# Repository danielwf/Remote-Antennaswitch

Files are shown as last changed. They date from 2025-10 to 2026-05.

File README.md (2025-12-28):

# ESP32 Antenna Switch 

for the Remote Club Station of [DARC Bremen (i04)](https://darc.de/i04)\
\
**This is a draft!** \
There is no guarantee of functionality. Use at your own risk. 

## Description

The antenna switch can be controlled via the ESP32 either by USB or WiFi. Two buttons can be connected for local control. The switched inputs and outputs are also indicated by LEDs.  
The 3 inputs and 5 outputs are switched using two bistable relays per connection (Finder 40.31.6.006.0000). These are controlled by drivers that can be put into sleep mode between switching operations (DRV8833PWP). This reduces power consumption and minimizes interference from busy switching regulators. In addition, the USB port of the ESP32 is sufficient for the power supply.  
The relay drivers are controlled via an I2C 16-bit port expander (MCP23017).  
In addition, a PWR/SWR meter is available via an I2C AD converter (ADS1115IDGS). This is used to prevent switching during transmission. It can also be used for transmitter-independent measurement to display transmission power and SWR in the remote software.  

Since both the relay switching and the reading of the SWR bridge are communicated via I2C, other controllers can also be used if necessary. It is also possible to connect several boards together. For this purpose, the I2C addresses can be easily adjusted via the solder pads.  

## Built

**Kicad 9:**
You maybe need the KiCad symbol and footprint for the ESP32 Mini(Wemos D1 Mini) [https://github.com/r0oland/ESP32_mini_KiCad_Library](https://github.com/r0oland/ESP32_mini_KiCad_Library) - Thanks to [Johannes Rebling](https://github.com/r0oland)

[Schematic](schematic.pdf)

**Hardware:**
Everything you need to prepare your PCB ordering with KiCAD is included. It is best to use a corresponding KiCAD plugin for this.  
In "BOM.ods" you will find the material list with links to the item numbers at Mouser and Reichelt. In the table, you can easily adjust how many devices the parts should be ordered for (as of Oct-25).  
The BOM includes a housing that is well suited for this purpose. The drill holes for the circuit board can be easily marked with an unassembled PCB (which should be done first). "Panels.svg" contains the drill holes and labels for the buttons, LEDs, and connection sockets. These can be produced using a vinyl cutter or laser engraver, for example. The easiest way to create the USB socket is to drill a 14 mm hole and produce a cover for it using a 3D printer. A template for this is also included.  
Once the parts have been assembled, the Arduino code for the ESP32 can be uploaded. You will find this in “AntennaSwitch-ESP32.ino”. For later OTA updates via the web interface, you can use “AntennaSwitch-ESP32.ino.bin”.  

## Usage WIFI
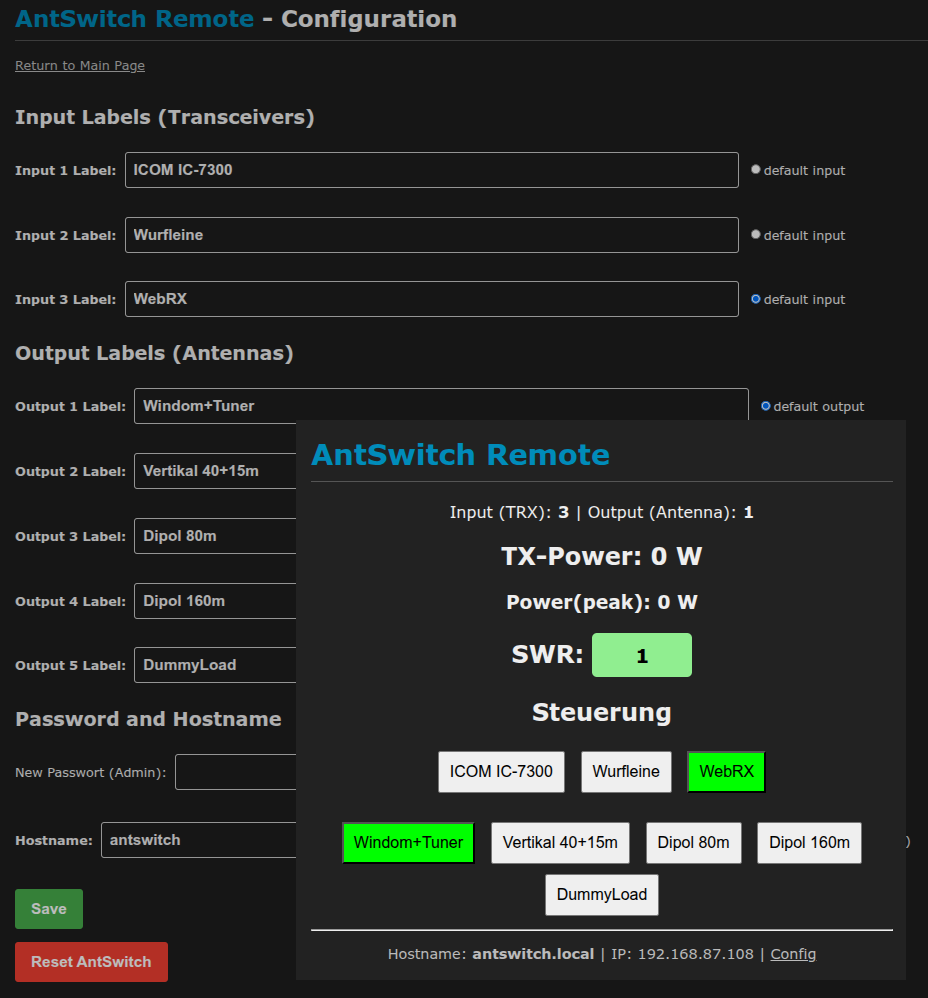
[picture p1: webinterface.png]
 After you have uploaded the Arduino code to the ESP32, you must connect to the “AntSwitch-Config” Wi-Fi network and set up the desired Wi-Fi network via the captive portal. 
Once the device is connected to your home network, you can configure it via 'https://antswitch.local' such as a new host name and the labels for the connectors. **Default password for 'admin' is 'antswitch'**.  
You can also switch via API (example: you want to use CURL in your shell/script, maybe in combination with rigctld). Examples: 
- http://antswitch.local/api/status (for JSON-Status)
- http://antswitch.local/api/switch?input=1 (set input to 1)
- http://antswitch.local/api/switch?output=2 (set output to 2)
Setup via API:
- http://antswitch.local/api/switch?iLabel1=IC-7300 (set Label of input 1)
- http://antswitch.local/api/switch?oLabel2=Windom-Antenna (set Label of output 2)
- http://antswitch.local/api/switch?defaultInput=1 (set default input after switch-on)
- http://antswitch.local/api/switch?defaultOutput=2 (set default output after switch-on)
- http://antswitch.local/api/status?maxTxPower=380 (Calibration of SWR-Meter acc to windings on transformer- or just try out and compare to other SWR-Meter)

## Usage USB-serial
The device can also be controlled via the USB-serial interface (115200 baud). With “GET:NET” you can display the current IP address.  
Serial commands: 
```
       ____DESCRIPTION__________INPUT_________________________RESPONSE___________________________________  
       Switching  
       Switch Input (TRX)          SET:I<Index>                  ACK:I<CurrentInput>,O<CurrentOutput>  
                                                                ERR:BLOCKED_TX (if P_fwd > 5.0W)  
       Switch Output (Antenna)     SET:O<Index>                  ACK:I<CurrentInput>,O<CurrentOutput>  
                                                                ERR:BLOCKED_TX (if P_fwd > 5.0W)  
       ___________________________________________________________________________________________________
       Configuration
       Set Input Label             SET_LABEL I <Index> <Label>   ACK:LABEL_OK
                                                                ERR:INVALID_LENGTH
       Set Output Label            SET_LABEL O <Index> <Label>   ACK:LABEL_OK
                                                                ERR:INVALID_LENGTH
       Set Default Input           SET_DEFAULT I <Index>         ACK:DEFAULT_OK
                                                                ERR:INVALID_INDEX
       Set Default Output          SET_DEFAULT O <Index>         ACK:DEFAULT_OK
                                                                ERR:INVALID_INDEX
       Set Admin Password          SET_PASS <Password>           ACK:PASS_OK
                                                                ERR:INVALID_LENGTH (min 8 chars)
       ___________________________________________________________________________________________________
       Status and Measurements
       Get All Status & Meas.      GET:STATUS                    ACK:STATUS,PF=x.x,PP=x.x,SWR=x.xx
       Get Forward Power (Formatted) GET:PF                        ACK:PF=x.x
       Get Peak Power (Formatted)  GET:PP                        ACK:PP=x.x
       Get SWR Value (Formatted)   GET:SWR                       ACK:SWR=x.xx
       Get Forward Power (Numeric) NUM:PF                        [x.x] (Unformatted numeric value)
       Get Peak Power (Numeric)    NUM:PP                        [x.x] (Unformatted numeric value)
       Get SWR Value (Numeric)     NUM:SWR                       [x.xx] (Unformatted numeric value)
       Get IP and Hostname         GET:NET                       ACK:NET,IP=x.x.x.x,HOST=<Hostname>
       Get Input Label             GET_LABEL I <Index>           ACK:LABEL_I<Index>=<Label>
       Get Output Label            GET_LABEL O <Index>           ACK:LABEL_O<Index>=<Label>
```

## Contributing

Pull requests are welcome. For major changes, please open an issue first
to discuss what you would like to change.

## License

[CC BY-SA 4.0](https://creativecommons.org/licenses/by-sa/4.0/) 

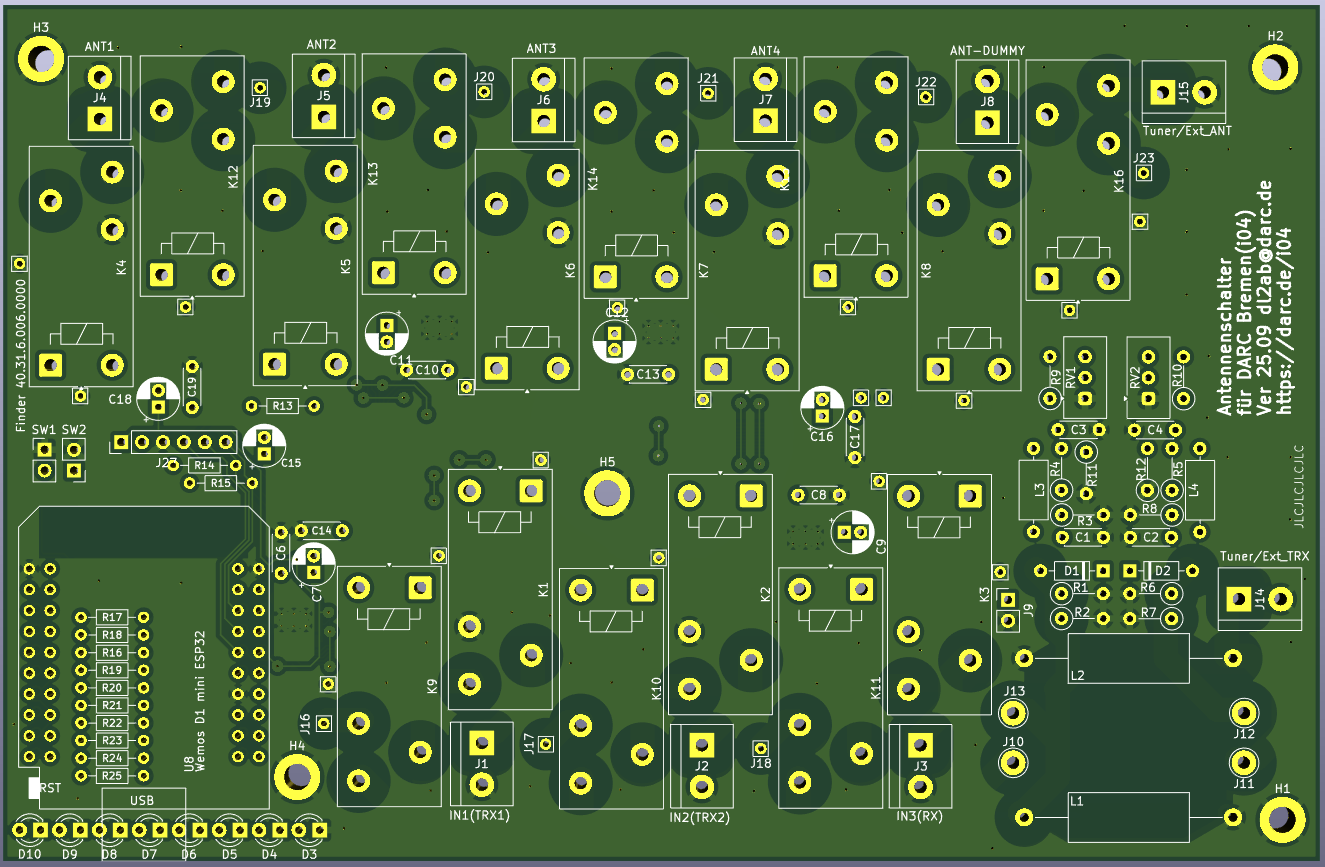
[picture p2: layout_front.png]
(Layout front)

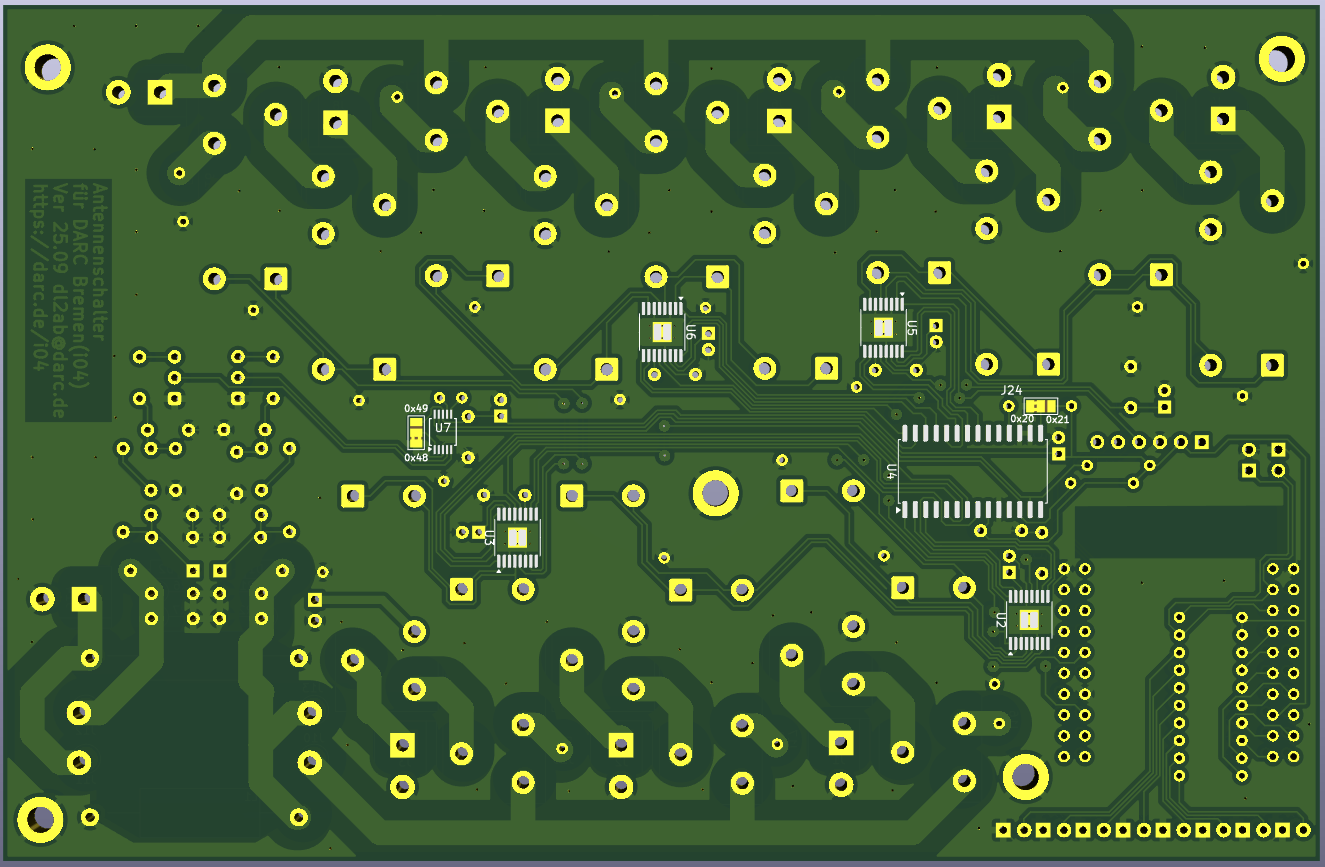
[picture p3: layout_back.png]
(Layout back)


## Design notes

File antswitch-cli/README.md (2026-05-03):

The antenna switch can be controlled via a browser interface or a serial interface. No special software is required for either method.  
However, it should be noted that a serial connection is not necessarily recommended if, for example, common-mode currents are expected at the switch due to an unsuitable antenna. Generally, a connection via the station's Wi-Fi network is recommended.  
There are some use cases where you might want to control a Wi-Fi-connected antenna switch using the Linux shell.  
This is now possible with Antswitch-CLI.  
  
antswitch-cli.config:  
Configuration of addresses and commands (admin users are only relevant for the web interface, see below)  
  
antswitch-cli.frq-map:  
Overview of frequencies, antennas, and tuners to be used.  
--> This file is helpful to other applications, e.g., for using remote transceiver software.  
Syntax: [Start Frequency (Hz)]-[End Frequency (Hz)]=[Antenna Number]|[TUNER (EXTERN/INTERN/AUS)]
  
antswitch-cli.port:  
Labels and Default Ports  
--> This file is helpful to other applications, e.g., for using remote transceiver software.  
(The script can read this information from the hardware and write it to the file)  
  
install.sh:  
Please read this beforehand; it contains information on installing the additional web interface.  
  
antswitch.php and antswitch-admin.php:  
Web interface for antenna switching via Antswitch-Cli.  
  
Although the antenna switch has its own web interface, there are reasons for not making it externally accessible. Furthermore, the antswitch-cli web interface is easier to embed as an iframe.  
  
The frequency map file can be edited and labels from the antenna switch can be imported via antswitch-admin.php. User management is not explained further here. However, it is advisable to install a PAM module for Apache, which, for example, manages access to the "/var/www/html/login" subfolder.

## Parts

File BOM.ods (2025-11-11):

 |  |  |  | per 07-Sep-2025 for 3 Units
Reference | Value | Footprint | Qty/Unit | Price/Unit | Builds | Qty/Batch | Price/Batch | Distributor | Link
C1,C2,C3,C4 | 1.2nF | Capacitor_THT:C_Disc_D4.3mm_W1.9mm_P5.00mm | 4 | 0,178 € | 3 | 12 | 2,14 € | Mouser | https://www.mouser.de/ProductDetail/810-FG28C0G2E122JNT6
C6,C8,C10,C13,C14,C17,C19 | 100nF | Capacitor_THT:C_Disc_D4.3mm_W1.9mm_P5.00mm | 7 | 0,077 € | 3 | 21 | 1,62 € | Mouser | https://www.mouser.de/ProductDetail/594-K104K15X7RF5WH5
C7,C9,C11,C12,C15,C16,C18 | 2.2uF | Capacitor_THT:CP_Radial_D5.0mm_P2.00mm | 7 | 0,124 € | 3 | 21 | 2,60 € | Mouser | https://www.mouser.de/ProductDetail/80-ESH225M050AC3KA
D1,D2 | BAT43 | Diode_THT:D_DO-35_SOD27_P7.62mm_Horizontal | 2 | 0,112 € | 3 | 6 | 0,67 € | Mouser | https://www.mouser.de/ProductDetail/511-BAT43
D3, D4, D5, D6, D7, D8, D9, D10 | LED1 | LED_THT:LED_D3.0mm | 8 | 0,147 € | 3 | 24 | 3,53 € | Mouser | https://www.mouser.de/ProductDetail/604-WP710A10CGCK
J1, J2, J3, J4, J5, J6, J7, J8, J14, J15 | IN/OUTPUT | PL-Connector | 10 | 1,720 € | 3 | 30 | 51,60 € | Mouser | https://www.mouser.de/ProductDetail/601-25-7350
J9 | ANT-RX | SMA-Connector | 1 | 8,320 € | 3 | 3 | 24,96 € | Mouser | https://www.mouser.de/ProductDetail/523-132142
L3,L4 | 47uH | Inductor_THT:L_Axial_L7.0mm_D3.3mm_P10.16mm_Horizontal_Fastron_MICC | 2 | 0,335 € | 3 | 6 | 2,01 € | Mouser | https://www.mouser.de/ProductDetail/871-B82141A1473J000
R1,R2,R6,R7 | 100R/1W | Resistor_THT:R_Axial_DIN0207_L6.3mm_D2.5mm_P5.08mm_Vertical | 4 | 0,140 € | 3 | 12 | 1,68 € | Mouser | https://www.mouser.de/ProductDetail/279-ROX1G100R
R3,R8 | 1M2 | Resistor_THT:R_Axial_DIN0207_L6.3mm_D2.5mm_P5.08mm_Vertical | 2 | 0,086 € | 3 | 6 | 0,52 € | Mouser | https://www.mouser.de/ProductDetail/603-MFR-25FRF52-1M2
R4,R5 | 8,2k | Resistor_THT:R_Axial_DIN0207_L6.3mm_D2.5mm_P5.08mm_Vertical | 2 | 0,072 € | 3 | 6 | 0,43 € | Mouser | https://www.mouser.de/ProductDetail/594-5063JD8K200FT
R9,R10 | 2.2k | Resistor_THT:R_Axial_DIN0207_L6.3mm_D2.5mm_P5.08mm_Vertical | 2 | 0,086 € | 3 | 6 | 0,52 € | Mouser | https://www.mouser.de/ProductDetail/594-MBB02070C2201FCT
R13,R14,R15,R17,R18 | 10k | Resistor_THT:R_Axial_DIN0204_L3.6mm_D1.6mm_P7.62mm_Horizontal | 5 | 0,068 € | 3 | 15 | 1,02 € | Mouser | https://www.mouser.de/ProductDetail/594-MBB02070C1002FRP
R16,R19,R20,R21,R22,R23,R24,R25 | 220 | Resistor_THT:R_Axial_DIN0204_L3.6mm_D1.6mm_P7.62mm_Horizontal | 8 | 0,072 € | 3 | 24 | 1,73 € | Mouser | https://www.mouser.de/ProductDetail/594-5063JD220R0FT
RV1,RV2 | 4.7k | Potentiometer_THT:Potentiometer_Vishay_T93YA_Vertical | 2 | 1,670 € | 3 | 6 | 10,02 € | Mouser | https://www.mouser.de/ProductDetail/72-T93YA472KT20
SW1, SW2 | Switch/Button | Push Button Panel Mount | 2 | 5,140 € | 3 | 6 | 30,84 € | Mouser | https://www.mouser.de/ProductDetail/612-PV2F640NN
U2,U3,U5,U6 | DRV8833PWP | Package_SO:HTSSOP-16-1EP_4.4x5mm_P0.65mm_EP3.4x5mm_Mask2.46x2.31mm_ThermalVias | 4 | 1,720 € | 3 | 12 | 20,64 € | Mouser | https://www.mouser.de/ProductDetail/595-DRV8833PWPR
U4 | MCP23017_SO | Package_SO:SOIC-28W_7.5x17.9mm_P1.27mm | 1 | 1,390 € | 3 | 3 | 4,17 € | Mouser | https://www.mouser.de/ProductDetail/579-MCP23017-E-SO
U7 | ADS1115IDGS | Package_SO:TSSOP-10_3x3mm_P0.5mm | 1 | 5,410 € | 3 | 3 | 16,23 € | Mouser | https://www.mouser.de/ProductDetail/595-ADS1115IDGST
Delivery |  |  |  |  |  |  | 0,00 € | Mouser
Total Mouser | 176,92 € | https://www.mouser.de/ProjectManager/ProjectDetail.aspx?AccessID=3c516e5cf0
U8 | Wemos D1 mini ESP32 | ESP32_mini:ESP32_mini | 1 | 10,500 € | 3 | 3 | 31,50 € | Reichelt | https://www.reichelt.de/de/de/shop/produkt/d1_mini_pro_-_esp32-wroom_board_cp2104-357465
Metal Housing | TEKO 385 | 253 x 160 x 70 | 1 | 41,700 € | 3 | 3 | 125,10 € | Reichelt | https://www.reichelt.de/de/de/shop/produkt/alugehaeuse_253_x_160_x_70_mm_silber-21198
50 Screws M3x10 (for Connectors) | M3x10 | M3 | 1 | 1,750 € | 3 | 3 | 5,25 € | Reichelt | https://www.reichelt.de/de/de/shop/produkt/pan_head_schrauben_kreuzschlitz_pzd_m3_10mm_50_stueck-65753
100 Washers 3.2mm | Washers | M3 | 1 | 1,550 € | 3 | 3 | 4,65 € | Reichelt | https://www.reichelt.de/de/de/shop/produkt/unterlegscheiben_3_2_mm_100_stueck-65763
100 Fan Washers 3.2mm | Fan Washers | M3 | 1 | 1,750 € | 3 | 3 | 5,25 € | Reichelt | https://www.reichelt.de/de/de/shop/produkt/faecherscheiben_3_2_mm_100_stueck-65789
100 Solder Lugs M3 | Solder Lugs | M3 | 1 | 3,400 € | 3 | 1 | 3,40 € | Reichelt | https://www.reichelt.de/de/de/shop/produkt/loetoesen_fuer_m3_100-er_pack-231423
100 Screw Nuts M3 | Screw Nuts | M3 | 1 | 4,550 € | 3 | 2 | 9,10 € | Reichelt | https://www.reichelt.de/de/de/shop/produkt/sechskantmuttern_edelstahl_a2_m3_100_stueck-72592
Feets for Housing | Rubber feet | M3 | 4 | 0,250 € | 3 | 12 | 3,00 € | Reichelt | https://www.reichelt.de/de/de/shop/produkt/anschraubpuffer_17_5_mm_9_mm_schwarz-8172
Spacer | Spacer | M3 | 5 | 0,290 € | 3 | 15 | 4,35 € | Reichelt | https://www.reichelt.de/de/de/shop/produkt/distanzhuelsen_metall_6-kant_m3_8mm-231466
K1,K2,K3,K4,K5,K6,K7,K8,K9,K10,K11,K12,K13,K14,K15,K16 | Finder 40.31.6.006.0000 | Relay_THT:Relay_SPDT_Finder_40.31 | 16 | 7,250 € | 3 | 48 | 348,00 € | Reichelt | https://www.reichelt.de/de/de/shop/produkt/bistabiles_steckrelais_6v_1_wechsler_10a-225229
L1/2 | BN43-202 | BN43-202 | 1 | 0,990 € | 3 | 3 | 2,97 € | Reichelt | https://www.reichelt.de/de/de/shop/produkt/doppellochkern_aussen_13_7_mm_innen_4_mm_al_2890-32310
Discount |  |  |  |  |  |  | -15,33 € | Reichelt
Delivery |  |  |  |  |  |  | 5,95 € | Reichelt
Total Reichelt | 533,19 € | https://www.reichelt.de/my/2288622
5x PCBs |  |  | Min. 5 | 10,05 | 1 | 1 | 10,05 € | JLCPCB
Delivery (DHL Express) |  |  |  | 18,32 | 1 | 1 | 18,32 € | JLCPCB
Total JLCPCB | 28,37 €
 |  |  |  |  |  | Total | 738,48 €

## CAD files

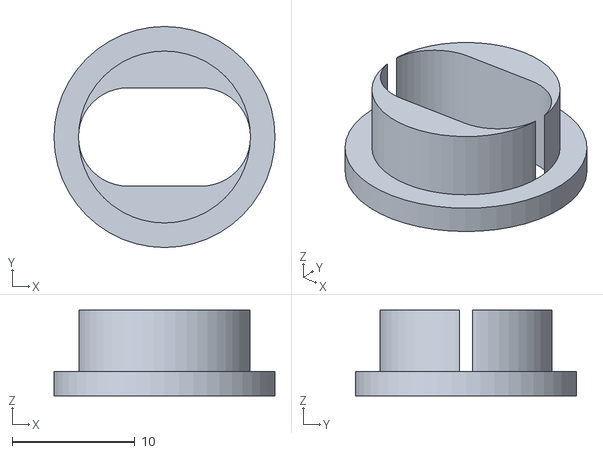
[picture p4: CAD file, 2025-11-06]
USB-C-14mm.stl
18.0 x 18.0 x 7.00

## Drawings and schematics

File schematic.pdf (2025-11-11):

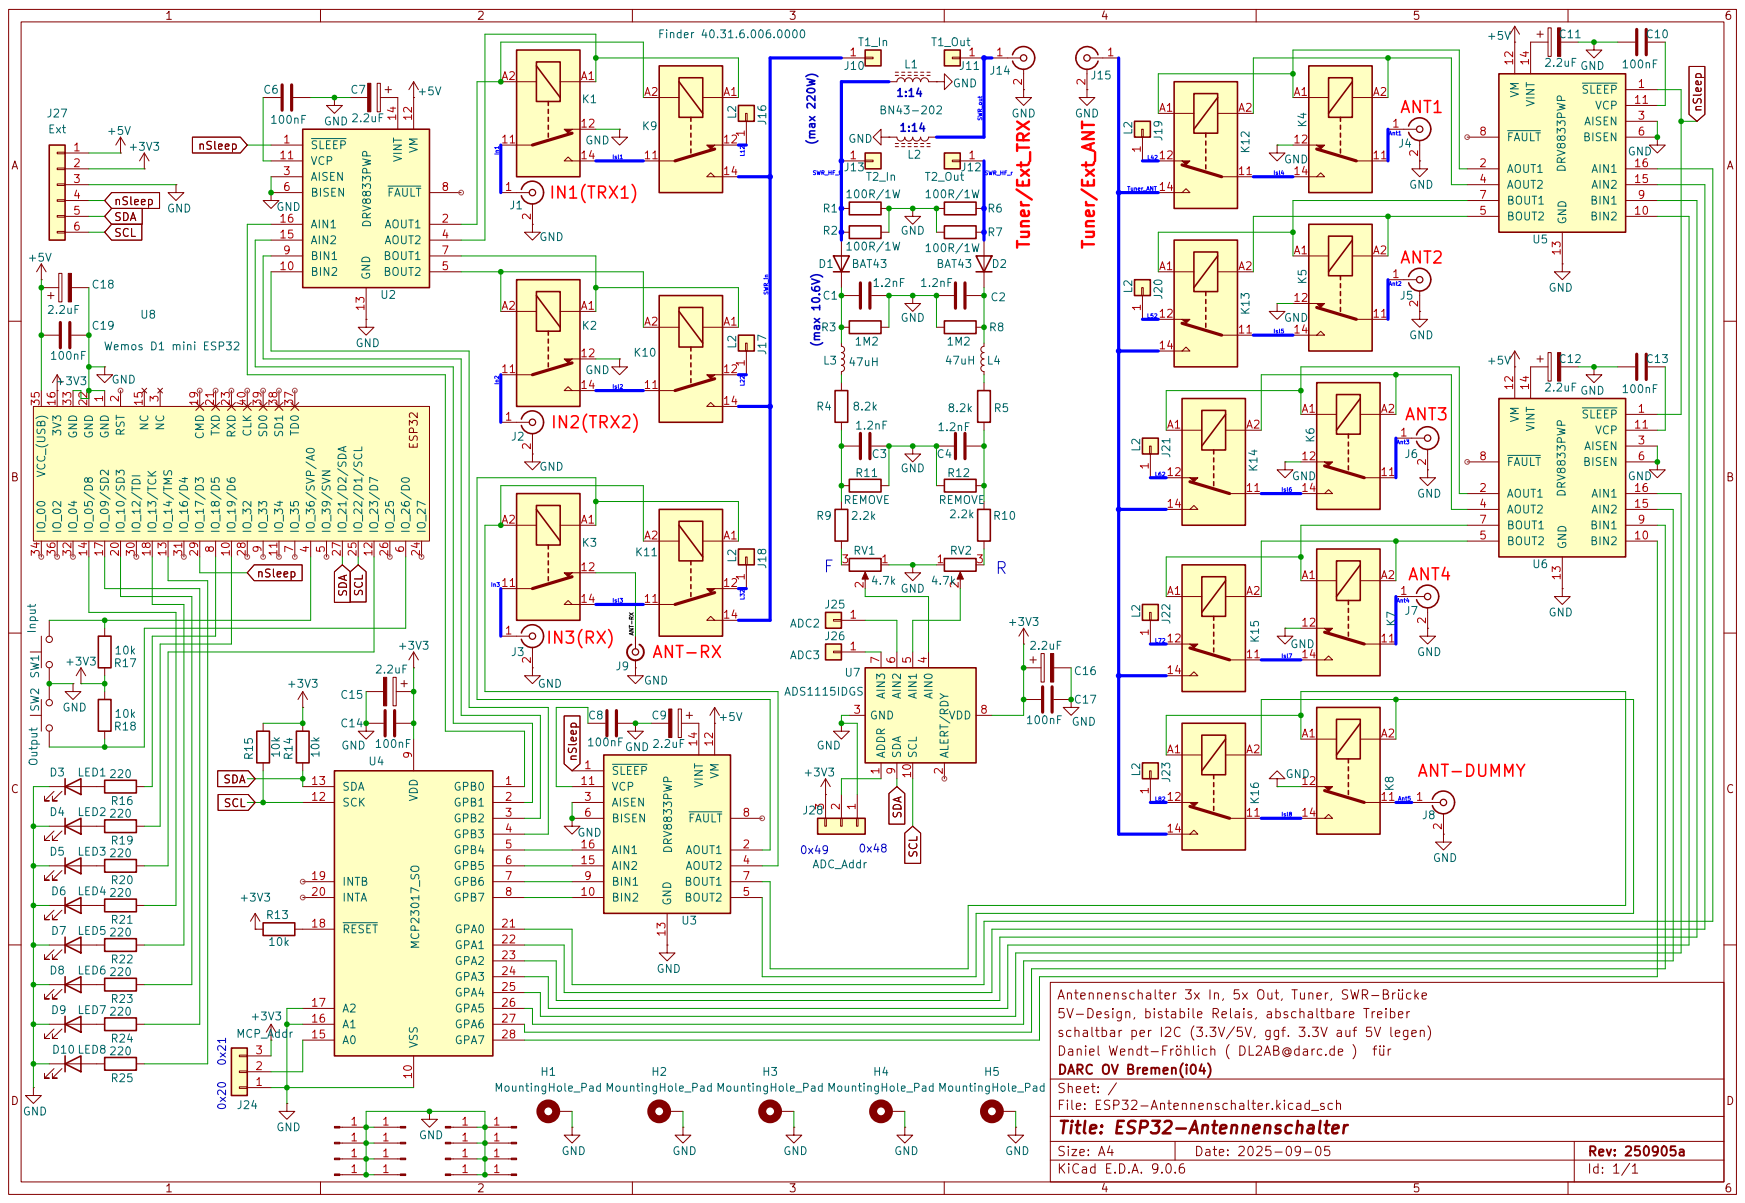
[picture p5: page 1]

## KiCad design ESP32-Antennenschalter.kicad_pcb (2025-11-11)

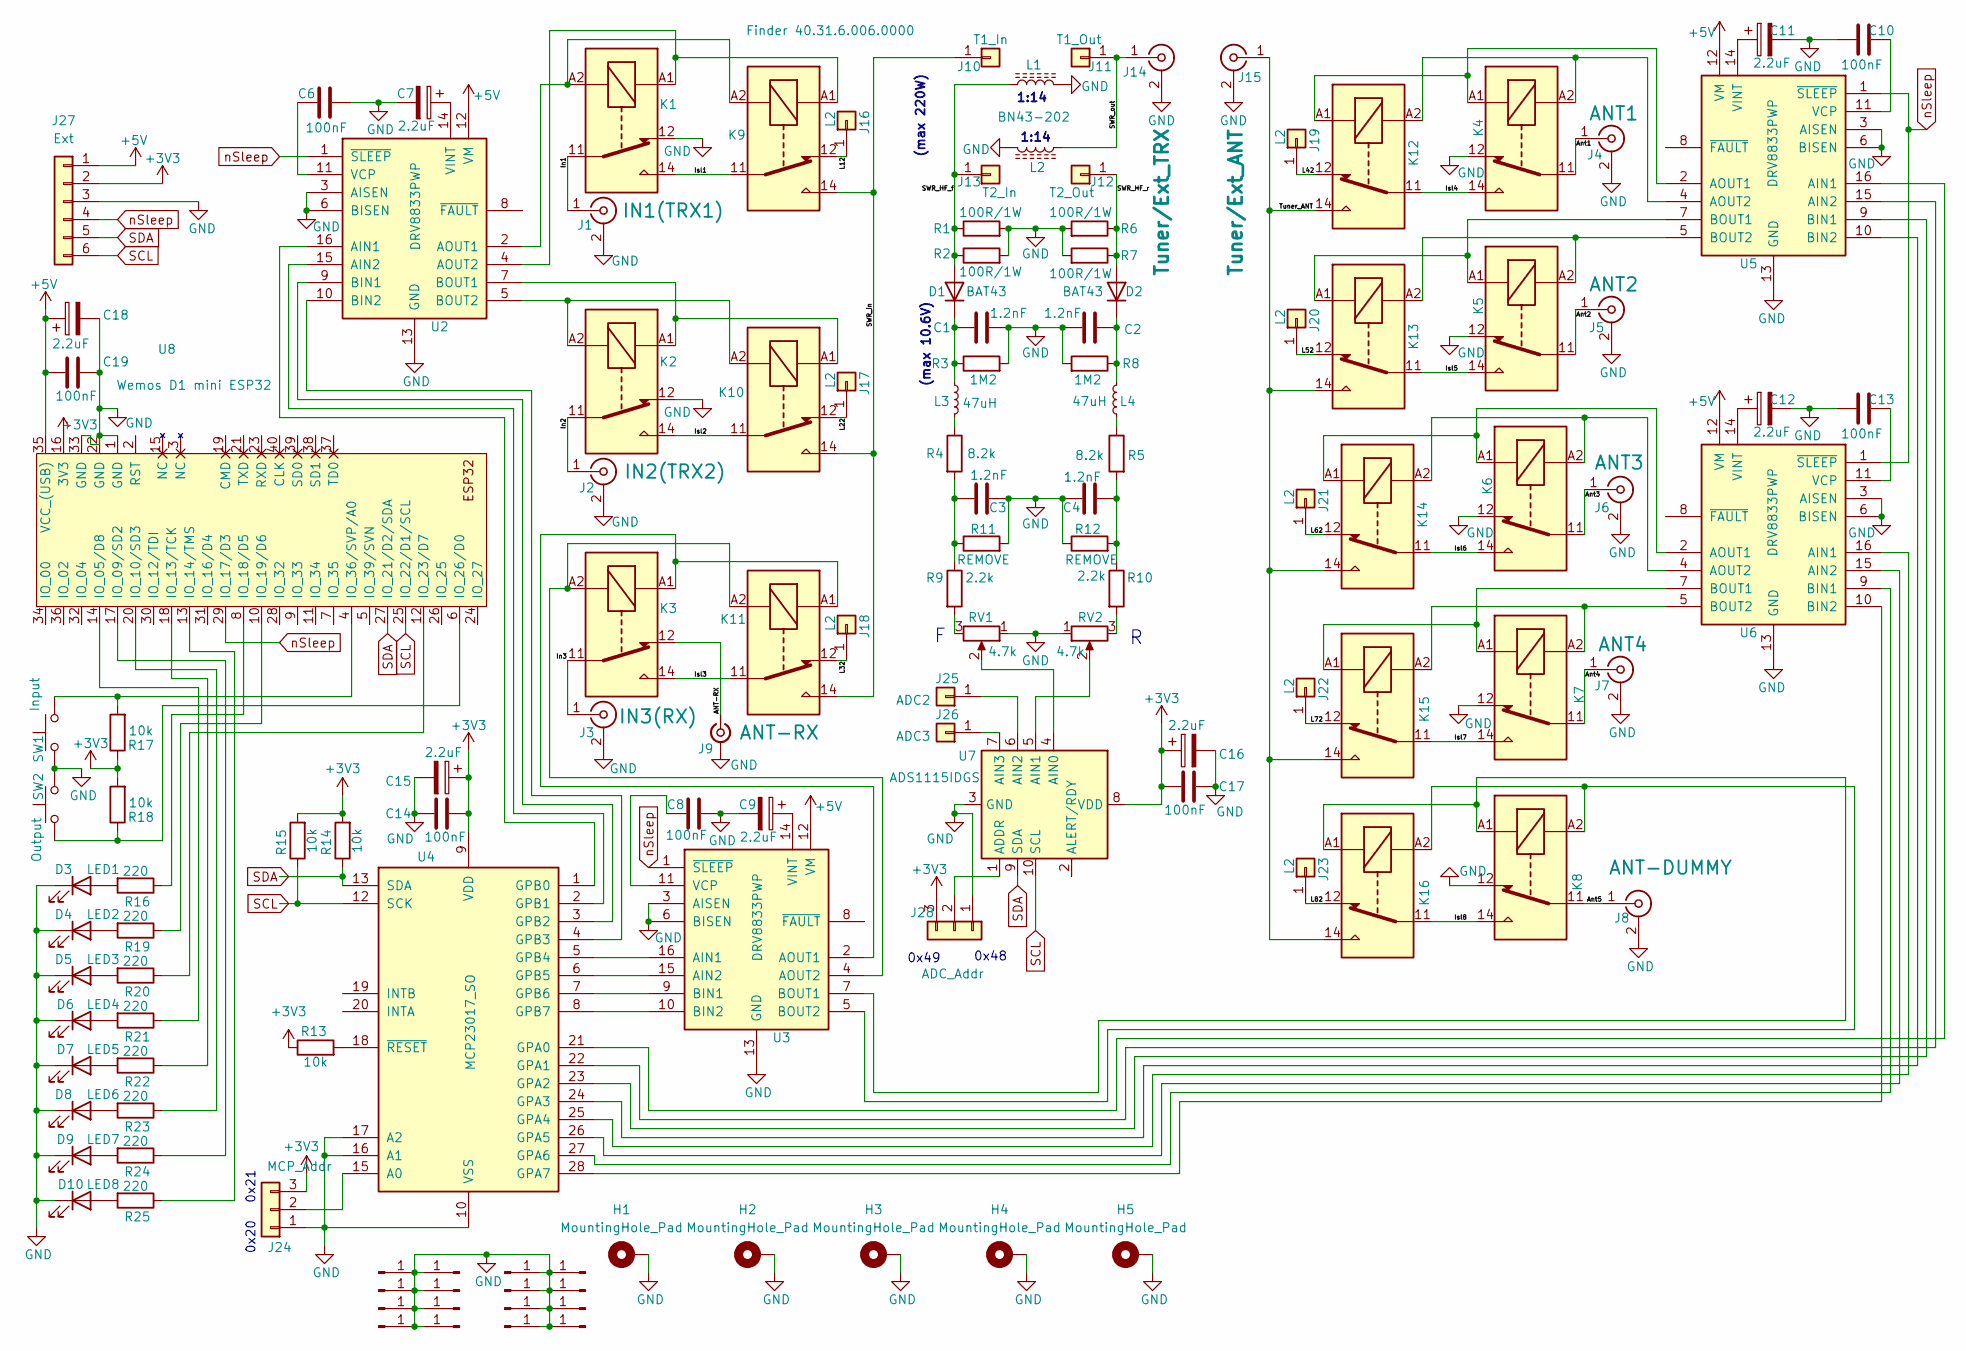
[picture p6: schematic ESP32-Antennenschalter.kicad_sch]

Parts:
C1, C2, C3, C4: 1.2nF; C_Disc_D4.3mm_W1.9mm_P5.00mm
C6, C8, C10, C13, C14, C17, C19: 100nF; C_Disc_D4.3mm_W1.9mm_P5.00mm
C7, C9, C11, C12, C15, C16, C18: 2.2uF; CP_Radial_D5.0mm_P2.00mm
D1, D2: BAT43; D_DO-35_SOD27_P7.62mm_Horizontal
D3: LED1; LED_D3.0mm
D4: LED2; LED_D3.0mm
D5: LED3; LED_D3.0mm
D6: LED4; LED_D3.0mm
D7: LED5; LED_D3.0mm
D8: LED6; LED_D3.0mm
D9: LED7; LED_D3.0mm
D10: LED8; LED_D3.0mm
H1, H2, H3, H4, H5: MountingHole_Pad; MountingHole_3.2mm_M3_DIN965_Pad_TopBottom
J1: IN1(TRX1); TerminalBlock_bornier-2_P5.08mm
J2: IN2(TRX2); TerminalBlock_bornier-2_P5.08mm
J3: IN3(RX); TerminalBlock_bornier-2_P5.08mm
J4: ANT1; TerminalBlock_bornier-2_P5.08mm
J5: ANT2; TerminalBlock_bornier-2_P5.08mm
J6: ANT3; TerminalBlock_bornier-2_P5.08mm
J7: ANT4; TerminalBlock_bornier-2_P5.08mm
J8: ANT-DUMMY; TerminalBlock_bornier-2_P5.08mm
J9: ANT-RX; PinHeader_1x02_P2.54mm_Vertical
J10: T1_In; Pin_D1.3mm_L11.0mm_LooseFit
J11: T1_Out; Pin_D1.3mm_L11.0mm_LooseFit
J12: T2_Out; Pin_D1.3mm_L11.0mm_LooseFit
J13: T2_In; Pin_D1.3mm_L11.0mm_LooseFit
J14: Tuner/Ext_TRX; TerminalBlock_bornier-2_P5.08mm
J15: Tuner/Ext_ANT; TerminalBlock_bornier-2_P5.08mm
J16, J17, J18, J19, J20, J21, J22, J23: L2; Pin_D0.7mm_L6.5mm_W1.8mm_FlatFork
J24: MCP_Addr; SolderJumper-3_P1.3mm_Bridged2Bar12_Pad1.0x1.5mm_NumberLabe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
J25: ADC2; Pin_D0.7mm_L6.5mm_W1.8mm_FlatFork
J26: ADC3; Pin_D0.7mm_L6.5mm_W1.8mm_FlatFork
J27: Ext; PinHeader_1x06_P2.54mm_Vertical
J28: ADC_Addr; SolderJumper-3_P1.3mm_Bridged2Bar12_Pad1.0x1.5mm_NumberLabe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
J29, J30, J31, J32, J33, J34, J35, J36, J37, J38, J39, J40, J41, J42, J43, J44: Conn_01x01_Pin; Pin_D0.7mm_L6.5mm_W1.8mm_FlatFork
K1, K2, K3, K4, K5, K6, K7, K8, K9, K10, K11, K12, K13, K14, K15, K16: Finder 40.31.6.006.0000; Relay_SPDT_Finder_40.31
L1, L2: BN43-202; L_Axial_L14.5mm_D5.8mm_P25.40mm_Horizontal_Fastron_HBCC
L3, L4: 47uH; L_Axial_L7.0mm_D3.3mm_P10.16mm_Horizontal_Fastron_MICC
R1, R2, R6, R7: 100R/1W; R_Axial_DIN0207_L6.3mm_D2.5mm_P5.08mm_Vertical
R3, R8: 1M2; R_Axial_DIN0207_L6.3mm_D2.5mm_P5.08mm_Vertical
R4, R5: 8.2k; R_Axial_DIN0207_L6.3mm_D2.5mm_P5.08mm_Vertical
R9, R10: 2.2k; R_Axial_DIN0207_L6.3mm_D2.5mm_P5.08mm_Vertical
R11, R12: REMOVE; R_Axial_DIN0207_L6.3mm_D2.5mm_P5.08mm_Vertical
R13, R14, R15, R17, R18: 10k; R_Axial_DIN0204_L3.6mm_D1.6mm_P7.62mm_Horizontal
R16, R19, R20, R21, R22, R23, R24, R25: 220; R_Axial_DIN0204_L3.6mm_D1.6mm_P7.62mm_Horizontal
RV1, RV2: 4.7k; Potentiometer_Vishay_T93YA_Vertical
SW1: Input; PinHeader_1x02_P2.54mm_Vertical
SW2: Output; PinHeader_1x02_P2.54mm_Vertical
U2, U3, U5, U6: DRV8833PWP; HTSSOP-16-1EP_4.4x5mm_P0.65mm_EP3.4x5mm_Mask2.46x2.31mm_The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
U4: MCP23017_SO; SOIC-28W_7.5x17.9mm_P1.27mm
U7: ADS1115IDGS; TSSOP-10_3x3mm_P0.5mm
U8: Wemos D1 mini ESP32; ESP32_mini

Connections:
+3V3: C14.1, C15.1, C16.1, C17.1, J24.3, J27.2, J28.3, R13.1, R14.2, R15.2, R17.1, R18.2, U4.9 (VDD), U7.8 (VDD), U8.16 (3V3)
+5V: C18.1, C19.2, J27.1, U2.12 (VM), U3.12 (VM), U5.12 (VM), U6.12 (VM), U8.35 (VCC_(USB))
/ANT-RX: J9.1 (In), K3.12
/Ant1: J4.1 (In), K4.11
/Ant2: J5.1 (In), K5.11
/Ant3: J6.1 (In), K6.11
/Ant4: J7.1 (In), K7.11
/Ant5: J8.1 (In), K8.11
/In1: J1.1 (In), K1.11
/In2: J2.1 (In), K2.11
/In3: J3.1 (In), K3.11
/Isl1: K1.14, K9.11
/Isl2: K2.14, K10.11
/Isl3: K3.14, K11.11
/Isl4: K4.14, K12.11
/Isl5: K5.14, K13.11
/Isl6: K6.14, K14.11
/Isl7: K7.14, K15.11
/Isl8: K8.14, K16.11
/L12: J16.1, K9.12
/L22: J17.1, K10.12
/L32: J18.1, K11.12
/L42: J19.1, K12.12
/L52: J20.1, K13.12
/L62: J21.1, K14.12
/L72: J22.1, K15.12
/L82: J23.1, K16.12
/SWR_HF_f: D1.2 (A), J13.1, L1.1, R1.1, R2.1
/SWR_HF_r: D2.2 (A), J12.1, R6.1, R7.1
/SWR_in: J10.1, K9.14, K10.14, K11.14
/SWR_out: J11.1, J14.1 (In), L2.1
/Tuner_ANT: J15.1 (In), K12.14, K13.14, K14.14, K15.14, K16.14
GND: C1.2, C2.2, C3.2, C4.1, C6.1, C7.2, C8.1, C9.2, C10.1, C11.2, C12.2, C13.1, C14.2, C15.2, C16.2, C17.2, C18.2, C19.1, D3.1 (K), D4.1 (K), D5.1 (K), D6.1 (K), D7.1 (K), D8.1 (K), D9.1 (K), D10.1 (K), H1.1, H2.1, H3.1, H4.1, H5.1, J1.2 (Ext), J2.2 (Ext), J3.2 (Ext), J4.2 (Ext), J5.2 (Ext), J6.2 (Ext), J7.2 (Ext), J8.2 (Ext), J9.2 (Ext), J14.2 (Ext), J15.2 (Ext), J24.1, J27.3, J28.1, J29.1, J30.1, J31.1, J32.1, J33.1, J34.1, J35.1, J36.1, J37.1, J38.1, J39.1, J40.1, J41.1, J42.1, J43.1, J44.1, K1.12, K2.12, K4.12, K5.12, K6.12, K7.12, K8.12, L1.2, L2.2, R1.2, R2.2, R3.2, R6.2, R7.2, R8.2, R11.2, R12.1, RV1.1, RV2.1, SW1.1, SW2.2, U2.3 (AISEN), U2.6 (BISEN), U2.13 (GND), U2.17 (GND), U3.3 (AISEN), U3.6 (BISEN), U3.13 (GND), U3.17 (GND), U4.10 (VSS), U4.16 (A1), U4.17 (A2), U5.3 (AISEN), U5.6 (BISEN), U5.13 (GND), U5.17 (GND), U6.3 (AISEN), U6.6 (BISEN), U6.13 (GND), U6.17 (GND), U7.3 (GND), U8.1 (GND), U8.22 (GND), U8.33 (GND)
unnamed: C3.1, R4.2, R9.1, R11.1
unnamed: C4.2, R5.2, R10.1, R12.2
unnamed: C1.1, D1.1 (K), L3.1, R3.1
unnamed: C2.1, D2.1 (K), L4.1, R8.1
unnamed: D3.2 (A), R16.2
unnamed: D4.2 (A), R19.2
unnamed: D5.2 (A), R20.2
unnamed: D6.2 (A), R21.2
unnamed: D7.2 (A), R22.2
unnamed: D8.2 (A), R23.2
unnamed: D9.2 (A), R24.2
unnamed: D10.2 (A), R25.2
unnamed: J24.2, U4.15 (A0)
unnamed: J25.1, U7.6 (AIN2)
unnamed: J26.1, U7.7 (AIN3)
unnamed: J28.2, U7.1 (ADDR)
unnamed: L3.2, R4.1
unnamed: L4.2, R5.1
unnamed: R9.2, RV1.3
unnamed: R10.2, RV2.3
unnamed: U2.16 (AIN1), U4.1 (GPB0)
unnamed: U2.15 (AIN2), U4.2 (GPB1)
unnamed: K1.A2, K9.A2, U2.2 (AOUT1)
unnamed: K1.A1, K9.A1, U2.4 (AOUT2)
unnamed: U2.9 (BIN1), U4.3 (GPB2)
unnamed: U2.10 (BIN2), U4.4 (GPB3)
unnamed: K2.A1, K10.A1, U2.7 (BOUT1)
unnamed: K2.A2, K10.A2, U2.5 (BOUT2)
unnamed: C6.2, U2.11 (VCP)
unnamed: C7.1, U2.14 (VINT)
unnamed: U3.16 (AIN1), U4.5 (GPB4)
unnamed: U3.15 (AIN2), U4.6 (GPB5)
unnamed: K3.A1, K11.A1, U3.2 (AOUT1)
unnamed: K3.A2, K11.A2, U3.4 (AOUT2)
unnamed: U3.9 (BIN1), U4.7 (GPB6)
unnamed: U3.10 (BIN2), U4.8 (GPB7)
unnamed: K8.A1, K16.A1, U3.7 (BOUT1)
unnamed: K8.A2, K16.A2, U3.5 (BOUT2)
unnamed: C8.2, U3.11 (VCP)
unnamed: C9.1, U3.14 (VINT)
unnamed: U4.21 (GPA0), U5.16 (AIN1)
unnamed: U4.22 (GPA1), U5.15 (AIN2)
unnamed: U4.23 (GPA2), U5.9 (BIN1)
unnamed: U4.24 (GPA3), U5.10 (BIN2)
unnamed: U4.25 (GPA4), U6.16 (AIN1)
unnamed: U4.26 (GPA5), U6.15 (AIN2)
unnamed: U4.27 (GPA6), U6.9 (BIN1)
unnamed: U4.28 (GPA7), U6.10 (BIN2)
unnamed: R13.2, U4.18 (~RESET)
unnamed: K4.A1, K12.A1, U5.2 (AOUT1)
unnamed: K4.A2, K12.A2, U5.4 (AOUT2)
unnamed: K5.A1, K13.A1, U5.7 (BOUT1)
unnamed: K5.A2, K13.A2, U5.5 (BOUT2)
unnamed: C10.2, U5.11 (VCP)
unnamed: C11.1, U5.14 (VINT)
unnamed: K6.A1, K14.A1, U6.2 (AOUT1)
unnamed: K6.A2, K14.A2, U6.4 (AOUT2)
unnamed: K7.A1, K15.A1, U6.7 (BOUT1)
unnamed: K7.A2, K15.A2, U6.5 (BOUT2)
unnamed: C13.2, U6.11 (VCP)
unnamed: C12.1, U6.14 (VINT)
unnamed: RV1.2, U7.4 (AIN0)
unnamed: RV2.2, U7.5 (AIN1)
unnamed: R21.1, U8.14 (IO_05/D8)
unnamed: R24.1, U8.17 (IO_09/SD2)
unnamed: R23.1, U8.20 (IO_10/SD3)
unnamed: R22.1, U8.18 (IO_13/TCK)
unnamed: R25.1, U8.13 (IO_14/TMS)
unnamed: R16.1, U8.8 (IO_18/D5)
unnamed: R19.1, U8.10 (IO_19/D6)
unnamed: R20.1, U8.12 (IO_23/D7)
unnamed: R18.1, SW2.1, U8.6 (IO_26/D0)
unnamed: R17.2, SW1.2, U8.4 (IO_36/SVP/A0)
SCL: J27.6, R15.1, U4.12 (SCK), U7.10 (SCL), U8.25 (IO_22/D1/SCL)
SDA: J27.5, R14.1, U4.13 (SDA), U7.9 (SDA), U8.27 (IO_21/D2/SDA)
nSleep: J27.4, U2.1 (~SLEEP), U3.1 (~SLEEP), U5.1 (~SLEEP), U6.1 (~SLEEP), U8.29 (IO_17/D3)

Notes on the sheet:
(max 10.6V)
0x20
0x49
0x48
(max 220W)
1:14
0x21

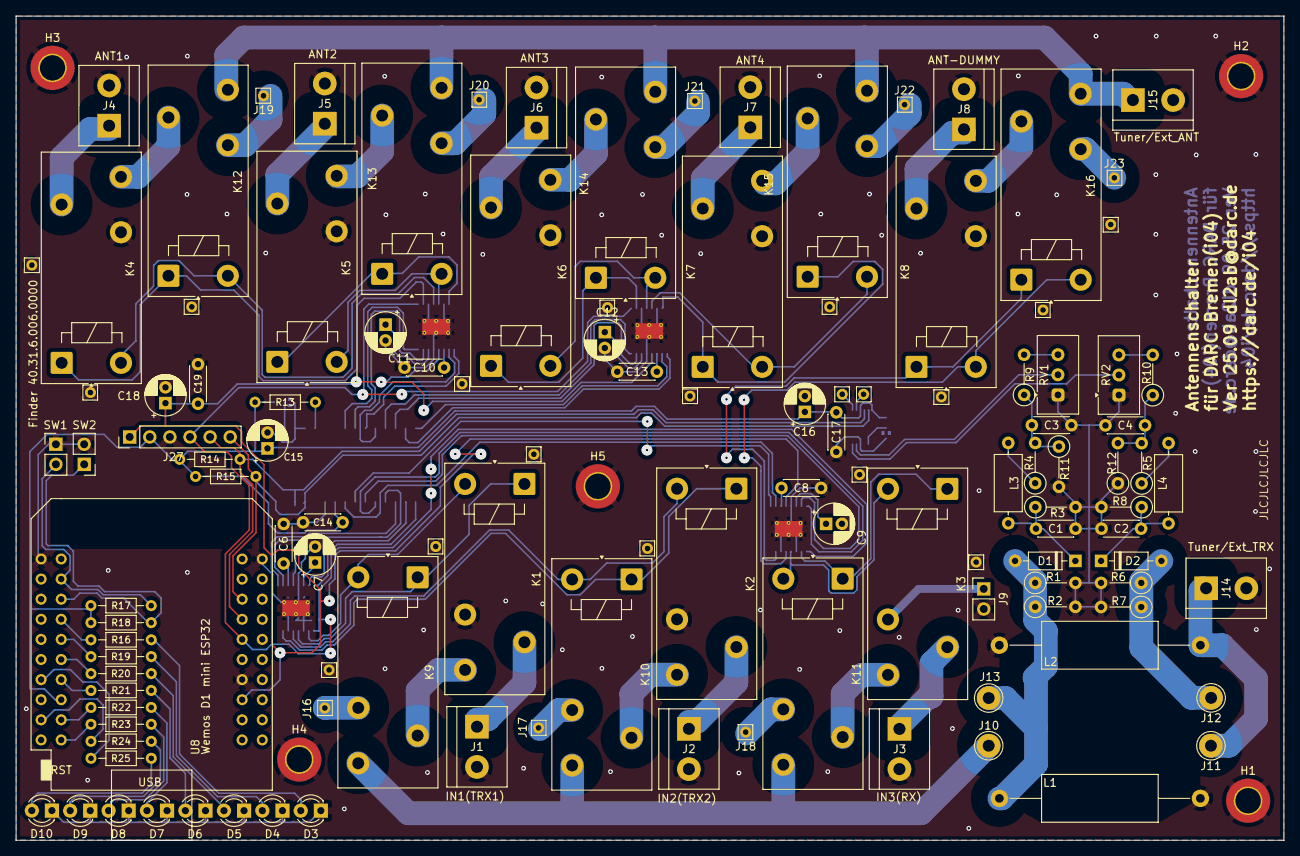
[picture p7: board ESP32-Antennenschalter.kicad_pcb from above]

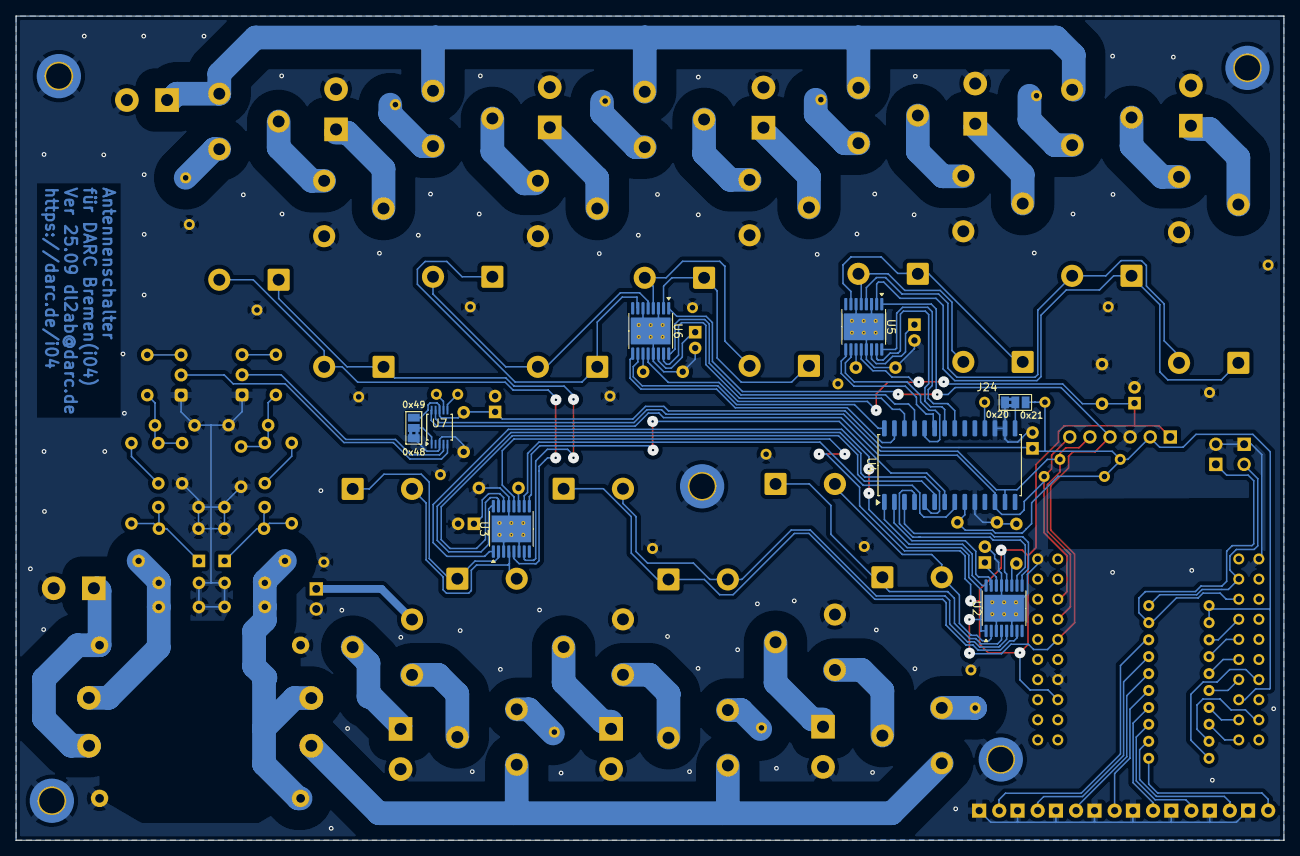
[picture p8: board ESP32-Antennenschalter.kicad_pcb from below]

Board: 2 copper layers, 160.2 x 104.1 mm, 133 parts (8 on the bottom side), 109 nets.

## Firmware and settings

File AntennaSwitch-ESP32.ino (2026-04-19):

#define ANTSWITCH_REMOTE_VERSION 26041901
//
//    .----------------------------------------------------------------------------------------------------------------------------------------------------------------.
//    |                                                                 "AntSwitch Remote" with ESP32                                                                  |
//    '----------------------------------------------------------------------------------------------------------------------------------------------------------------'
//     by Daniel Wendt-Fröhlich, DL2AB (daniel.w-froehlich@aetherfoton.de, dl2ab@darc.de) - AI supported by Google Gemini
//     License CC-by-SA 4.0 - Sep-Oct 2025 - Bremen(GER) -- https://creativecommons.org/licenses/by-sa/4.0/
//
//     Schematic, PCB and Code: https://github.com/danielwf/Remote-Antennaswitch    
// 
//     Used Libs:
//     - Install "esp32" by Espressif via Arduino-Board-Manager and select "Wemos D1 ESP32" (you have to scroll down the unsorted list)
//     - Install via Arduino Library Manager:
//        - "WiFiManager" by tzapu * https://github.com/tzapu/WiFiManager 
//        - "Adafruit_MCP23017" by adafruit * https://github.com/adafruit/Adafruit-MCP23017-Arduino-Library 
//        - "Adafruit ADS1X15" by adafruit * https://github.com/adafruit/Adafruit_ADS1X15 
//                      ----------> * THANK YOU FOR YOUR WORK! <----------
//
// 
//     IF YOU LOOSE ADMIN-CONFIG-PASSWORD OR NEED A "FACTORY-RESET" FOR ANOTHER REASON:
//         - Reupload Sketch with -> [Tools] -> "Erase All Flash Before Sketch Upload" -> "enabled"
//         - Disable it after reupload or you have to connect Wifi after every sketch update via Arduino IDE ;)   
//
//     ------------------------------------------------Usage // Serial Commands------------------------------------------------------
//     First Boot: Connect to "antswitch"-Wifi and use the Captive Portal for connecting to an existing Wifi-Network
//     After Wifi-Connect: IP is shown after bootup in serial console (or use the DHCP-Client list in your Wifi-Router)
//     Webbrowser: Use http://antswitch.local oder http://[IP] for switching, http://[IP]/config for config (default user: admin; default password: antswitch)
//     curl: http://[IP]/api/switch?input=1 (example to set input to 1) and http://[IP]/api/status for JSON-Status
//     Serial commands (115200 baud):
//       ____DESCRIPTION__________INPUT_________________________RESPONSE___________________________________
//       Switching
//       Switch Input (TRX)          SET:I<Index>                  ACK:I<CurrentInput>,O<CurrentOutput>
//                                                                ERR:BLOCKED_TX (if P_fwd > 5.0W)
//       Switch Output (Antenna)     SET:O<Index>                  ACK:I<CurrentInput>,O<CurrentOutput>
//                                                                ERR:BLOCKED_TX (if P_fwd > 5.0W)
//       ___________________________________________________________________________________________________
//       Configuration
//       Set Input Label             SET_LABEL I <Index> <Label>   ACK:LABEL_OK
//                                                                ERR:INVALID_LENGTH
//       Set Output Label            SET_LABEL O <Index> <Label>   ACK:LABEL_OK
//                                                                ERR:INVALID_LENGTH
//       Set Default Input           SET_DEFAULT I <Index>         ACK:DEFAULT_OK
//                                                                ERR:INVALID_INDEX
//       Set Default Output          SET_DEFAULT O <Index>         ACK:DEFAULT_OK
//                                                                ERR:INVALID_INDEX
//       Set Admin Password          SET_PASS <Password>           ACK:PASS_OK
//                                                                ERR:INVALID_LENGTH (min 8 chars)
//       ___________________________________________________________________________________________________
//       Status and Measurements
//       Get All Status & Meas.      GET:STATUS                    ACK:STATUS,PF=x.x,PP=x.x,SWR=x.xx
//       Get Forward Power (Formatted) GET:PF                        ACK:PF=x.x
//       Get Peak Power (Formatted)  GET:PP                        ACK:PP=x.x
//       Get SWR Value (Formatted)   GET:SWR                       ACK:SWR=x.xx
//       Get Forward Power (Numeric) NUM:PF                        [x.x] (Unformatted numeric value)
//       Get Peak Power (Numeric)    NUM:PP                        [x.x] (Unformatted numeric value)
//       Get SWR Value (Numeric)     NUM:SWR                       [x.xx] (Unformatted numeric value)
//       Get IP and Hostname         GET:NET                       ACK:NET,IP=x.x.x.x,HOST=<Hostname>
//       Get Input Label             GET_LABEL I <Index>           ACK:LABEL_I<Index>=<Label>
//       Get Output Label            GET_LABEL O <Index>           ACK:LABEL_O<Index>=<Label>
//       ___________________________________________________________________________________________________
//       Errors
//       Unknown Command                                       ERR:UNKNOWN_CMD
//       Invalid Index (e.g., I4 for 3 inputs)                 ERR:INVALID_INDEX
//       Invalid Format                                        ERR:FORMAT_PASS / ERR:FORMAT_LABEL / ...
//       ___________________________________________________________________________________________________//
//     ------------------------------------------------Connections----------------------------------------------------------
//       buttonInput: A0/IO36/SVP
//       buttonOutput: D0/IO26
//
//       ledOut5(led1): D5/IO18/GPIO18
//       ledOut4(led2): D6/IO19/GPIO19
//       ledOut3(led3): D7/IO23/GPOI23
//       ledOut2(led4): D8/IO05/GPIO05
//       ledOut1(led5): TCK/IO13/GPIO13
//       ledIn3(led6): SD3/IO10/GPIO10
//       ledIn2(led7): SD2/IO09/GPIO09
//       ledIn1(led8): TMS/IO14/GPIO14
//       
//       nSleep: D3/IO17/GPIO17
//
//       SDA: D2/IO21/SDA
//       SCL: D1/IO22/SCL
//       
//    .----------------------------------------------------------------------------------------------------------------------------------------------------------------.
//    |                                                          Libraries, Settings, Functions                                                                        |
//    '----------------------------------------------------------------------------------------------------------------------------------------------------------------'
//
//    .---------------------------------------------------------------------------------------.
//    |             WIFI-Settings (1/2), Configuration and Memory (1/2                        |
//    '---------------------------------------------------------------------------------------'

#include <WiFi.h>
#include <ESPmDNS.h>
#include <WebServer.h>
#include <WiFiManager.h>
#include <Preferences.h>

const byte MAX_LABEL_LENGTH = 16;
const byte MAX_PASSWORD_LENGTH = 32;
struct Config {                            // initiale Konfiguration, kann alles später auf der Config-Seite geändert werden
  int version = 1;
  char hostname[40] = "antswitch";
  char configPassword[MAX_PASSWORD_LENGTH] = "antswitch"; // Standardpasswort (User: Admin)
  char inputLabels[3][MAX_LABEL_LENGTH] = {"TRX 1", "TRX 2", "TRX 3"}; // Input-Labels
  char outputLabels[5][MAX_LABEL_LENGTH] = {"Antenna 1", "Antenna 2", "Antenna 3", "Antenna 4", "Antenna 5"}; // Output-Labels
  bool defaultInputEnabled[3] = {true, false, false}; // Standardzustand-Checkboxen
  bool defaultOutputEnabled[5] = {true, false, false, false, false}; // Standardzustand-Checkboxen
  float maxTxPowerW = 100.0; // NEU: Maximale Sendeleistung in Watt (Standard 100.0W)
};
Config appConfig;
Preferences appPrefs;
WiFiManager wm; 
WiFiManagerParameter custom_hostname("hostname", "Hostname", appConfig.hostname, 40);
const char* apName = "AntSwitch-Config";
const char* apPassword = "antswitch"; 

//    .---------------------------------------------------------------------------------------.
//    |             PWR/SWR-Meter                                                             |
//    '---------------------------------------------------------------------------------------'
#include <Adafruit_ADS1X15.h> // supports ADS1115
Adafruit_ADS1115 ads;
int16_t rawForward = 0; // Gemessen an AIN0
int16_t rawReflected = 0; // Gemessen an AIN1
const float ADS_FULLSCALE = 4.096;
const float ADS_MAX_VALUE = 32767.0; // Max. Rohwert (15-Bit, da +/-)
const float MAX_CAL_VOLTAGE = 3.3;  // 3.3V am ADS1115 entspricht maximaler Leistung

void setupADS() {
  ads.begin(0x48);
  ads.setGain(GAIN_ONE); //max Signal can be 3.3V... 2.048V is too low, so we have to set the gain to max 4.096V. 
  ads.setDataRate(RATE_ADS1115_475SPS); //setzt die Datenrate auf 475SPS, um Busgeschwindigkeit zu erhöhen.
}

float voltageF = 0.0;
float voltageR = 0.0;
float powerF = 0.0;       // current Power                                       
float powerPeak = 0.0;    // MaxPower for current/last TX
float swr = 1.0;          // SWR
void readSWR(){
  rawForward = ads.readADC_SingleEnded(1);
  rawReflected = ads.readADC_SingleEnded(0);
  voltageF = ((float)rawForward / ADS_MAX_VALUE) * ADS_FULLSCALE;
  if (voltageF < 0.0) voltageF = 0.0;
  voltageR = ((float)rawReflected / ADS_MAX_VALUE) * ADS_FULLSCALE;
  if (voltageR < 0.0) voltageR = 0.0;
  const float dynamicVoltsSqToWattsFactor = appConfig.maxTxPowerW / (MAX_CAL_VOLTAGE * MAX_CAL_VOLTAGE);
  powerF = (voltageF * voltageF) * dynamicVoltsSqToWattsFactor;
  if (powerF >= powerPeak) powerPeak = powerF;
  if (voltageF <= 0.005) { 
    swr = 1.0;
  } else {
    float rho = voltageR / voltageF;     // Reflexionskoeffizient ρ = U_R / U_F
    if (rho >= 1.0) {                    // Wenn U_R >= U_F (d.h. ρ >= 1.0), ist SWR unendlich oder sehr hoch
        swr = 9.9;                       // Setze auf maximalen Anzeigewert
    } else {
        swr = (1.0 + rho) / (1.0 - rho); 
    }
  }
  if (swr > 9.9) swr = 9.9;
}

#define TX_HOLD_TIME 5000       // 5000 ms = 5 Sekunden Haltezeit nach letztem TX
#define SWR_INTERVAL_TX 50      // 50 ms Leserate im aktiven TX-Betrieb
#define SWR_INTERVAL_IDLE 500   // 500 ms Leserate im Leerlauf (IDLE)
unsigned long lastSWRRead = 0;             // Zeitpunkt der letzten SWR-Messung
unsigned long lastTxTime = 0;              // Zeitpunkt des letzten Power > 0 Ereignisses
volatile bool isSwitching = false;         // Zustand Relaisschaltung. Hintergrund: Das Auslesen des SWR-Meters "blockiert" Zeit auf dem I2C-Bus, die beim Umschalten nicht nötig ist. 
void handleSWRReading() {
    unsigned long currentTime = millis();
    unsigned long currentInterval;
    if (isSwitching) return;               // keine Messung, wenn Relais geschaltet werden. 
    if ( (currentTime - lastTxTime) < TX_HOLD_TIME) { // Bestimmt das Leseintervall basierend auf der letzten TX-Aktivität
        currentInterval = SWR_INTERVAL_TX;         // Zustand: TX-Modus (oder Haltezeit läuft noch)
    } else {
        currentInterval = SWR_INTERVAL_IDLE; // Zustand: Leerlauf (länger als 10s kein TX)
        powerPeak = 0.0; // powerPeak zurücksetzen, da wir in den IDLE-Modus gewechselt sind.
    }

    if (currentTime - lastSWRRead >= currentInterval) {     // prüft, ob Intervall abgelaufen ist
        readSWR();                                          // Messung durchführen
        lastSWRRead = currentTime;
        if (powerF > 0.1) lastTxTime = currentTime;         // prüft, ob gesendet wird und aktualisiert den TX-Zeitstempel
    }
}

//    .---------------------------------------------------------------------------------------.
//    |             Relais                                                                    |
//    '---------------------------------------------------------------------------------------'
#define nSleep 17 //Sleep für DRV8833
#include <Wire.h>
#include <Adafruit_MCP23X17.h>
Adafruit_MCP23X17 mcp;
const int NUM_INPUTS = 3;
const int NUM_OUTPUTS = 5;
int currentInput = 1; // Standardmäßig Transceiver 1
int currentOutput = 1; // Standardmäßig Antenne 1
const float MAX_SWITCHING_POWER_W = 5.0; // Max. erlaubte Leistung in Watt für Umschaltvorgänge

#define mcpInput1  0b0000001100000000
#define mcpInput2  0b0000110000000000
#define mcpInput3  0b0011000000000000
#define mcpOutput1 0b0000000000000011
#define mcpOutput2 0b0000000000001100
#define mcpOutput3 0b0000000000110000
#define mcpOutput4 0b0000000011000000
#define mcpOutput5 0b1100000000000000
#define mcpRelOn   0b0101011001010101 //bits for Input1 reversed, see "error" in schematic U2/AOUT1+AOUT2
#define mcpRelOff  0b1010100110101010 
#define mcpRelNull 0x0000
const uint16_t mcpInputRelais[NUM_INPUTS] = {mcpInput1, mcpInput2, mcpInput3};
const uint16_t mcpOutputRelais[NUM_OUTPUTS] = {mcpOutput1, mcpOutput2, mcpOutput3, mcpOutput4, mcpOutput5};
uint16_t mcpValue = 0x0000;

void setupMcp() {
  mcp.begin_I2C(0x20); // 0x20 ist die Adresse des MCP23017
  for (int i = 0; i < 16; i++) {
    mcp.pinMode(i, OUTPUT);  // Setze alle 16 Pins als OUTPUT
    mcp.digitalWrite(i, LOW); // Alle Spulen auf inaktiv setzen
  }
}

void initInputRelais(){
  digitalWrite(nSleep, HIGH);
  delay(10);
  for (byte i=0; i < NUM_INPUTS; i++){
    mcpValue = mcpInputRelais[i] & mcpRelOn;
    mcp.writeGPIOAB(mcpValue);
    delay(10); //<-------------------Kurzer(!) Impuls setzt die Relaispule!
    mcp.writeGPIOAB(mcpRelNull);
    delay(10);
  }
  digitalWrite(nSleep, LOW);
}

void initOutputRelais(){
  digitalWrite(nSleep, HIGH);
  delay(10);
  for (byte i=0; i < NUM_OUTPUTS; i++){
    mcpValue = mcpOutputRelais[i] & mcpRelOn;
    mcp.writeGPIOAB(mcpValue);
    delay(10); //<-------------------Kurzer(!) Impuls setzt die Relaispule!
    mcp.writeGPIOAB(mcpRelNull);
    delay(10);
  }
  digitalWrite(nSleep, LOW);
}

bool switchOutput(byte outputRelais){
  if (powerF > MAX_SWITCHING_POWER_W) {
    return false; // Blockiert Relaisumschaltung, wenn gesendet wird und gibt 0-Wert zurück
  }
  isSwitching = true;           // sperrt SWR-Messung
  initOutputRelais();
  digitalWrite(nSleep, HIGH);
  mcpValue = mcpOutputRelais[(outputRelais-1)] & mcpRelOn;
  mcp.writeGPIOAB(mcpValue); 
  delay(100); //<-------------------langer Impuls setzt Relaisspule zurück
  mcp.writeGPIOAB(mcpRelNull);
  for (byte i=0; i < NUM_OUTPUTS; i++){
    if ( i!= (outputRelais-1) ) {
      mcpValue = mcpOutputRelais[i] & mcpRelOff;
      mcp.writeGPIOAB(mcpValue);
      delay(10); //<-------------------Kurzer(!) Impuls setzt die Relaispule!
      mcp.writeGPIOAB(mcpRelNull);
      delay(10);
    }
  }
  digitalWrite(nSleep, LOW);
  isSwitching = false;          // gibt SWR-Messung wieder frei
  setOutputLed(outputRelais);
  currentOutput = outputRelais;
  return true;
}

bool switchInput(byte inputRelais){
  if (powerF > MAX_SWITCHING_POWER_W) {
    return false; // Blockiert Relaisumschaltung, wenn gesendet wird und gibt 0-Wert zurück
  }
  isSwitching = true;           // sperrt SWR-Messung
  initInputRelais();
  digitalWrite(nSleep, HIGH);
  mcpValue = mcpInputRelais[(inputRelais-1)] & mcpRelOn;
  mcp.writeGPIOAB(mcpValue); 
  delay(100);
  mcp.writeGPIOAB(mcpRelNull);
  for (byte i=0; i < NUM_INPUTS; i++){
    if ( i!= (inputRelais-1) ) {
      mcpValue = mcpInputRelais[i] & mcpRelOff;
      mcp.writeGPIOAB(mcpValue);
      delay(10); //<-------------------Kurzer(!) Impuls setzt die Relaispule!
      mcp.writeGPIOAB(mcpRelNull);
      delay(10);
    }
  }
  digitalWrite(nSleep, LOW);
  isSwitching = false;          // gibt SWR-Messung wieder frei
  setInputLed(inputRelais);
  currentInput = inputRelais;
  return true;
}

void applyDefaultState() {
    bool inputSet = false;
    bool outputSet = false;
    for (int i = 0; i < NUM_INPUTS; i++) {          // STANDARD-EINGANG ANWENDEN
        if (appConfig.defaultInputEnabled[i]) {
            switchInput(i + 1); 
            inputSet = true;
            break; 
        }
    }
    if (!inputSet) {
        switchInput(currentInput); 
    }
    for (int i = 0; i < NUM_OUTPUTS; i++) {         // STANDARD-AUSGANG ANWENDEN
        if (appConfig.defaultOutputEnabled[i]) {
            switchOutput(i + 1); 
            outputSet = true;
            break; 
        }
    }
    if (!outputSet) {
        switchOutput(currentOutput);
    }
}

//    .---------------------------------------------------------------------------------------.
//    |             LEDs and buttons                                                          |
//    '---------------------------------------------------------------------------------------'
#define ledIn1 14
#define ledIn2 9
#define ledIn3 10
#define ledOut1 13
#define ledOut2 5
#define ledOut3 23
#define ledOut4 19
#define ledOut5 18
#define buttonInput 36
#define buttonOutput 26
const int INPUT_LED_PINS[] = {ledIn1, ledIn2, ledIn3};
const int OUTPUT_LED_PINS[] = {ledOut1, ledOut2, ledOut3, ledOut4, ledOut5};

void setupGpios() {
    pinMode(buttonInput, INPUT);  // "INPUT" is correct. We use external PullUp-Resistors for the buttons.
    pinMode(buttonOutput, INPUT); 
    for (int i = 0; i < NUM_INPUTS; i++) {
        pinMode(INPUT_LED_PINS[i], OUTPUT);
        digitalWrite(INPUT_LED_PINS[i], LOW);
    } 
    for (int i = 0; i < NUM_OUTPUTS; i++) {
        pinMode(OUTPUT_LED_PINS[i], OUTPUT);
        digitalWrite(OUTPUT_LED_PINS[i], LOW);
    }
    pinMode(nSleep, OUTPUT);
    digitalWrite(nSleep, LOW); 
}

void blinkCheck() {
    delay(200); 
    for (int i = 0; i < NUM_INPUTS; i++) {
        digitalWrite(INPUT_LED_PINS[i], HIGH);
        delay(100);
        digitalWrite(INPUT_LED_PINS[i], LOW);
    }
        for (int i = 0; i < NUM_OUTPUTS; i++) {
        digitalWrite(OUTPUT_LED_PINS[i], HIGH);
        delay(100);
        digitalWrite(OUTPUT_LED_PINS[i], LOW);
    }
}

void setInputLed(int inputIndex) {
  for (int i = 0; i < NUM_INPUTS; i++) {
    digitalWrite(INPUT_LED_PINS[i], LOW);
  }
  digitalWrite(INPUT_LED_PINS[inputIndex - 1], HIGH);      
}
void setOutputLed(int outputIndex) {
  for (int i = 0; i < NUM_OUTPUTS; i++) {
    digitalWrite(OUTPUT_LED_PINS[i], LOW);
  }
  digitalWrite(OUTPUT_LED_PINS[outputIndex - 1], HIGH);
}

unsigned long lastButtonTime = 0;
const long DEBOUNCE_DELAY_MS = 200; // Entprellzeit: 200ms
void switchButton() {
    unsigned long currentTime = millis();
    if (currentTime - lastButtonTime < DEBOUNCE_DELAY_MS) { // Prüfe, ob die Entprellzeit abgelaufen ist
        return;
    }
    if (digitalRead(buttonInput) == LOW) {            // 1. INPUT-Button (Pin 36) prüfen; LOW = Gedrückt
        lastButtonTime = currentTime;
        byte nextInput = (currentInput % NUM_INPUTS) + 1;
        switchInput(nextInput); // Versuche, zum nächsten Eingang zu schalten
        while(digitalRead(buttonInput) == LOW) { // Warte, bis der Button losgelassen wird (optional, aber gut für den Loop-Fluss)
            delay(5); 
        }
        return;
    }
    if (digitalRead(buttonOutput) == LOW) {     // 2. OUTPUT-Button (Pin 26) prüfe
        lastButtonTime = currentTime;
        byte nextOutput = (currentOutput % NUM_OUTPUTS) + 1;          // Versuche, zum nächsten Ausgang zu schalten
        switchOutput(nextOutput);
        while(digitalRead(buttonOutput) == LOW) {         // Warte, bis der Button losgelassen wird
            delay(5); 
        }
        return;
    }
}

//    .---------------------------------------------------------------------------------------.
//    |             WIFI-Settings (2/2), Config-AP                                            |
//    '---------------------------------------------------------------------------------------'
bool restartOnConfigTimeout = false;
void configModeCallback (WiFiManager *myWiFiManager) {
  Serial.print("Betrete den Konfigurationsmodus (Captive Portal). Verbinde mit dem AP: ");
  Serial.println(myWiFiManager->getConfigPortalSSID());
  // Wenn das Portal geschlossen wird UND wir den Timeout gesetzt hatten,
  // erzwingen wir den Neustart, um einen neuen Verbindungsversuch zu starten.
  if (restartOnConfigTimeout) {
      Serial.println("INFO: Captive Portal Timeout erreicht. Erzwinge Neustart.");
      delay(100); // Kurze Pause
      ESP.restart();
  }
}
void saveConfigCallback() {
  // WICHTIG: Diese Funktion bleibt leer, da sie nur der Callback des WiFiManagers ist.
}

void WLANbegin(){
  wm.setAPStaticIPConfig(IPAddress(10,0,1,1), IPAddress(10,0,1,1), IPAddress(255,255,255,0));
  wm.setDebugOutput(false);
  wm.setAPCallback(configModeCallback);
  wm.setSaveConfigCallback(saveConfigCallback);
  wm.setConfigPortalTimeout(180); // Setzt den Timeout auf 180 Sekunden (3 Minuten)
  restartOnConfigTimeout = true; // Wir wollen einen Neustart, wenn das Portal schließt
  if (!wm.autoConnect(apName, apPassword)) {
  } else {
    restartOnConfigTimeout = false; // Zurücksetzen, kein Neustart nötig
    WiFi.setHostname(appConfig.hostname);
    MDNS.begin(appConfig.hostname);
    Serial.print("Erfolgreich mit WLAN verbunden! http://");
    Serial.print(WiFi.localIP());
    Serial.println(" | http://" + String(appConfig.hostname) + ".local");
    startWebServer(); // Registriert Handler und ruft server.begin()
    // --- Task auf Core 0 starten, um die Web-Anfragen zu bearbeiten ---
    xTaskCreatePinnedToCore(
            webTask,       // Funktion, die den Webserver in der Schleife handled
            "WebServer",   
            4096,          
            NULL,          
            1,             
            NULL,          
            0              // Core 0
        );
  }
}
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
void loop() {
  handleSWRReading(); // liest das SWR-Meter (Intervalle werde in der Funktion gesteuert)
  handleSerialCommands(); // Serielle Steuerung
  switchButton();  //Nahbedienung per Buttons
}

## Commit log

2025-09-06 added vias for better shielding
    [ESP32-Antennenschalter.kicad_pcb]
2025-09-07 BOM (mouser, reichelt, prices for 3 units)
    [BOM.ods]
2025-10-23 Arduino-Code for Wemos D1 Mini ESP32
    See Code for Documentation
2025-10-26 repaired broken GND-connection of U2
    [ESP32-Antennenschalter.kicad_pcb]
2025-10-26 updated layout (repaired GND-connection at U2)
2025-10-26 Buttons and OTA-Update
2025-11-02 Added SVG template for labels and drill holes
    The drill holes for the PCB and case feet depend on the case. It is best to use the unassembled PCB to mark the corresponding holes.
    I would recommend drilling the holes for the LEDs first, inserting them, and soldering them to the PCB with wires.
2025-11-02 USB-C-Cover for 14mm drilling hole
    [USB-C-14mm.stl]
2025-11-06 Better Layout for LEDs
2025-11-06 wider opening
    [USB-C-14mm.stl]
2025-11-11 SWR-Meter: Remove R11,R23; Replace R4,R5 with 8.2K
    [BOM.ods, ESP32-Antennenschalter.kicad_pcb, ESP32-Antennenschalter.kicad_sch]
2025-11-11 added PWR/SWR-Calibration + some minor changes
2025-12-14 reset every 3min if not connected to known wifi
    After power failures, the antenna switch starts up faster than the WiFi router, causing the antenna switch to switch to WiFi configuration mode and remain there. To prevent this, the antenna switch now restarts after 3 minutes in WiFi configuration mode in order to establish the connection as soon as it is available. If the WiFi cannot be found, you have 3 minutes to connect to a new WiFi network ;)
    [AntennaSwitch-ESP32.ino]
2025-12-14 reset Antswitch after 3min in wifi-config
    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
    [AntennaSwitch-ESP32.ino]
2025-12-14 reset after 3min in wifi-config-mode
    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
    [AntennaSwitch-ESP32.ino]
2026-04-19 Add files via upload
    Power(peak) reset was not working. Reset-Level set to 0.1W
    [AntennaSwitch-ESP32.ino]
